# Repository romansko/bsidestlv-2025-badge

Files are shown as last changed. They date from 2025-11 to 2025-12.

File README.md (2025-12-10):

# BSidesTLV2025 Hardware CTF
Unlock the hidden secrets of the badge. What kind of secrets lie in waiting? Designed for security researchers and hardware enthusiasts, the BSidesTLV2025 badge is your ultimate mystery in digital exploration.

<p align = "center">
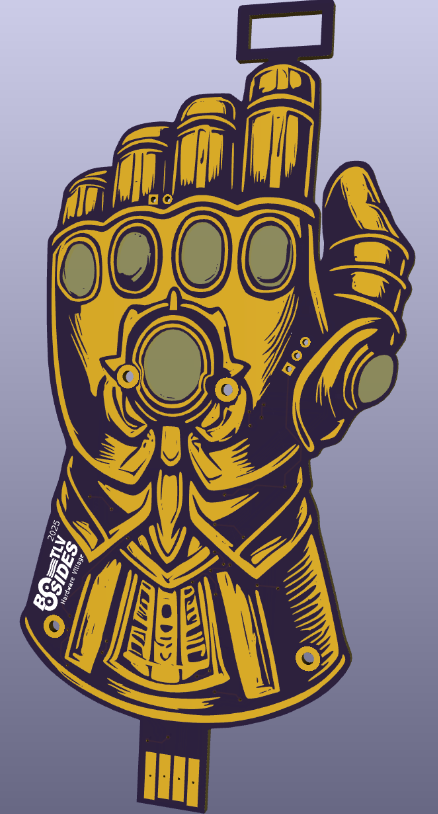
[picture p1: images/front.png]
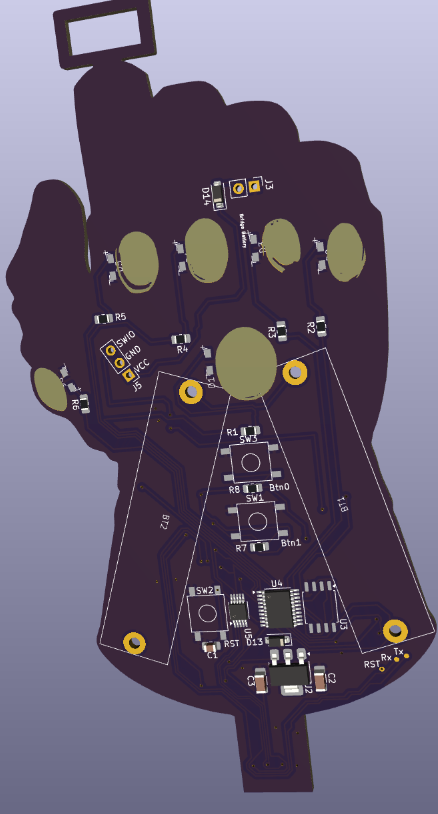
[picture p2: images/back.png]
     
</p>

### About The Project
The BSidesTLV2025 badge is a hardware hacking challenge. It is suitable for both novice and experienced tinkerers and hackers. It utilizes a low number of components to make the challenge easier to grasp, but holds in itself enough intricacies that will require the challenger a keen eye and sharp mind to solve all challenges.

To solve the challenge you will need to discover a series of flags, hidden inside the badge. Each one will help you unlock the next step in the challenge, to finally reveal the ultimate secret the badge holds.

## How to Solve
You, as the challenger, will face a couple of tricks on the hardware level. It is strongly recommended to identify which chips are used, find their datasheet and understand how they are connected. Then, dive into the software to understand how it is built and figure out what needs to be done to make the badge uncover its truth to you. All the software (except the encryption keys and the flags) is available here on this repository. It is recommended to try and reverse engineer the PCB before heading towards the `hw` folder.

### Source structure
* `aes.cpp` [AES implementation](https://github.com/kokke/tiny-AES-c)
* `main.cpp` Boot and Setup

... The rest is up to you. :-)

### You Will Need
Ultimately, no additional tools are required to solve the challenges. However, for hardcore external hacking, the following list is a recommended list of equipment that is suggested to solve the challenge:
* Multimeter
* Soldering Iron
* Jumper wires
* An external microcontroller (Any Arduino/RPi)

### Software
Please install the following software to be able to flash software to the device:
* [ch32fun](https://github.com/cnlohr/ch32fun/wiki/Installation) Follow install guide for toolchain and `minichlink` flash utility
* [Flash Update](https://swordofsecrets.com/update.html) Use online update tool to update the sword using preflashed bootloader

### Hardware
All PCB specs are provided here under `hw/`. This can be easily manufactured as well as paneled for a larger volume. There are no special requirements for this board's manufacturing process.

#### Bill of Materials
| Quantity | Component Description | Datasheet |
|---|---|---|
| 1 | CH32V003 RISC-V Microcontroller | [Datasheet](http://mcu.cz/images_articles/5007-CH32V003Reference-Manual.PDF) |
| 1 | AMS1117-3.3 LDO Voltage Regulator | [Datasheet](https://www.ti.com/lit/gpn/lm1117) |
| 1 | CH340N USB-toSerial | [Datasheet](https://cdn.sparkfun.com/assets/5/0/a/8/5/CH340DS1.PDF) |
| 1 | W25Q128JVSIQ 128MB NOR Flash | [Datasheet](https://www.mouser.co.il/datasheet/2/949/w25q128jv_revf_03272018_plus-1489608.pdf) |
| 1 | SMD 10 kOhms 0805 Resistor|  |
| 1 | SMD 100 kOhms 0805 Resistor |  |
| 3 | SMD 0.1 uF 0805 Capacitor |  |

<!-- LICENSE -->
## License

Distributed under the MIT License.

<p align="right">(<a href="#readme-top">back to top</a>)</p>

<!-- CONTACT -->
## Contact

Gili Yankovitch - [@GiliYankovitch](https://x.com/GiliYankovitch) - giliy@nyxsecurity.net

<!-- MARKDOWN LINKS & IMAGES -->
<!-- https://www.markdownguide.org/basic-syntax/#reference-style-links -->
[front]: images/front.png
[back]: images/back.png

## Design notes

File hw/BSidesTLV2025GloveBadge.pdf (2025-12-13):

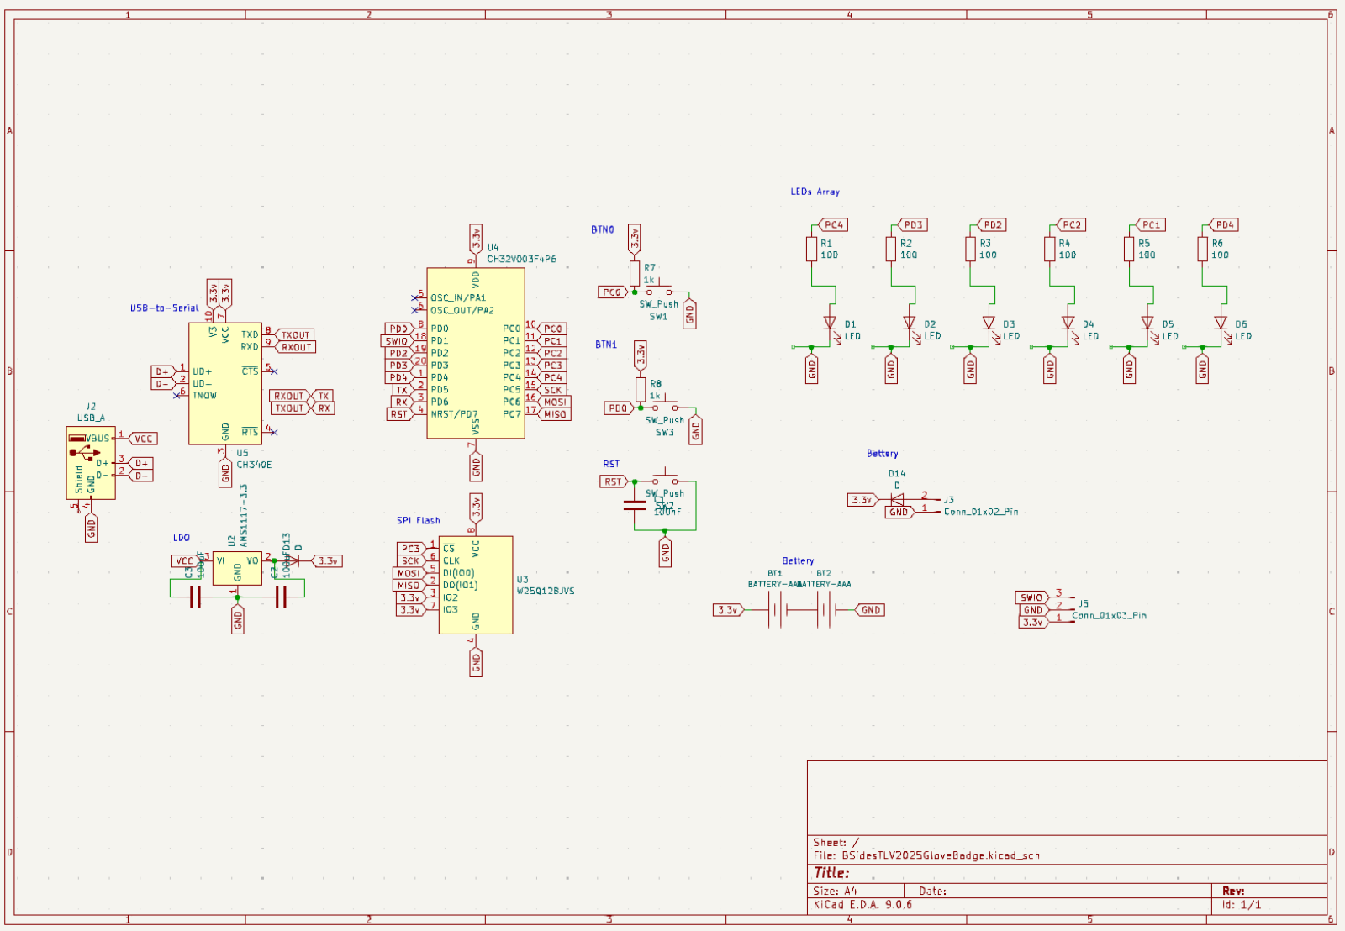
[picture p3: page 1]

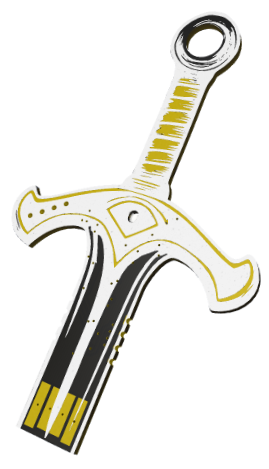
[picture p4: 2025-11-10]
images/sword.png

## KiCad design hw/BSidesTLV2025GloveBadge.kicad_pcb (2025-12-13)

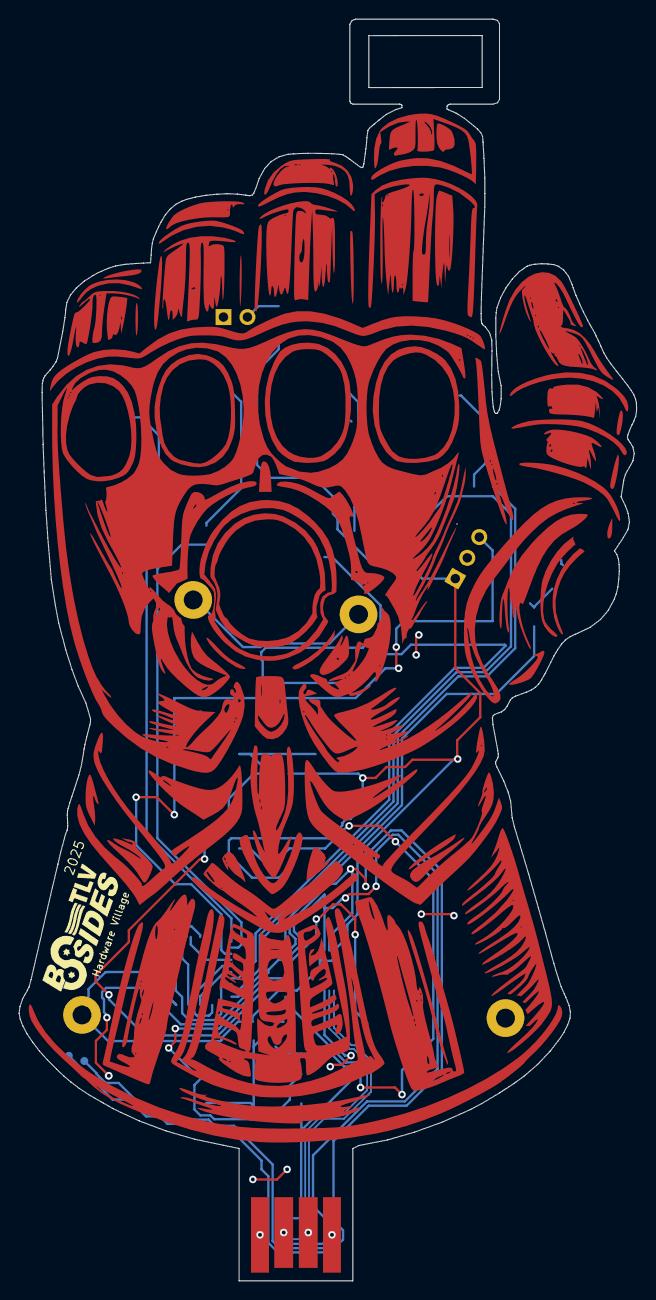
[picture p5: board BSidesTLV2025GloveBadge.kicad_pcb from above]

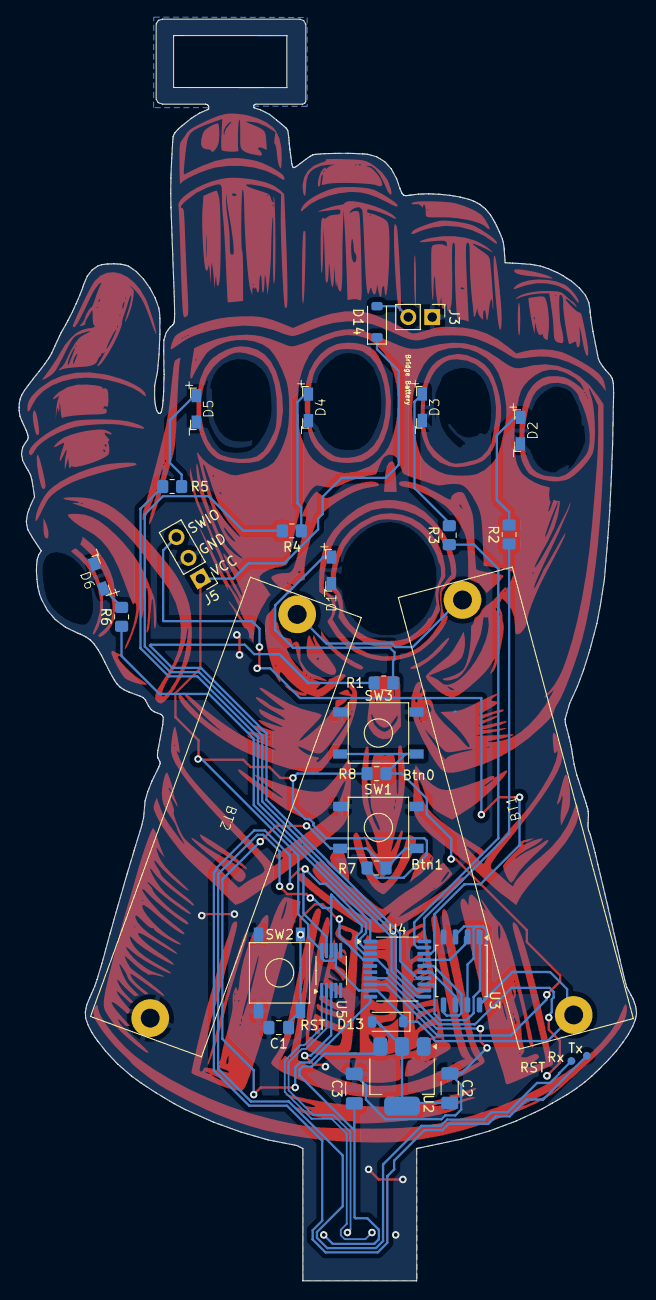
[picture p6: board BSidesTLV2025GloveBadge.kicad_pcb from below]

Board: 2 copper layers, 65.4 x 133.6 mm, 31 parts (30 on the bottom side), 30 nets.

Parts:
BT1, BT2: BATTERY-AAA; BH-AAA-A1AJ001
C1: 100nF; C_0805_2012Metric_Pad1.18x1.45mm_HandSolder
C2, C3: 100uF; C_1206_3216Metric_Pad1.33x1.80mm_HandSolder
D1, D2, D3, D4, D5, D6: LED; XL-2810
D13, D14: D; D_SOD-123
J2: USB_A; usb-PCB
J3: Conn_01x02_Pin; PinHeader_1x02_P2.54mm_Vertical
J5: Conn_01x03_Pin; PinHeader_1x03_P2.54mm_Vertical
R1, R2, R3, R4, R5, R6: 100; R_0805_2012Metric_Pad1.20x1.40mm_HandSolder
R7, R8: 1k; R_0805_2012Metric_Pad1.20x1.40mm_HandSolder
SW1, SW2, SW3: SW_Push; SMD-BTN-6x6-4Pin
U2: AMS1117-3.3; SOT-223-3_TabPin2
U3: W25Q128JVS; SOIC-8_5.23x5.23mm_P1.27mm
U4: CH32V003F4P6; TSSOP-20_4.4x6.5mm_P0.65mm
U5: CH340E; MSOP-10_3x3mm_P0.5mm

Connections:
3.3v: BT1.PWR@ (+), D13.1 (K), D14.1 (K), J5.1, R7.1, R8.1, U3.3 (IO2), U3.7 (IO3), U3.8 (VCC), U4.9 (VDD), U5.7 (VCC), U5.10 (V3)
D+: J2.3 (D+), U5.1 (UD+)
D-: J2.2 (D-), U5.2 (UD-)
GND: BT2.GND@ (-), C1.2, C2.1, C3.2, D1.1 (K), D2.1 (K), D3.1 (K), D4.1 (K), D5.1 (K), D6.1 (K), J2.4 (GND), J3.1, J5.2, SW1.1, SW2.1, SW3.1, U2.1 (GND), U3.4 (GND), U4.7 (VSS), U5.3 (GND)
MISO: U3.2 (DO(IO1)), U4.17 (PC7)
MOSI: U3.5 (DI(IO0)), U4.16 (PC6)
unnamed: BT1.GND@ (-), BT2.PWR@ (+)
unnamed: D1.2 (A), R1.2
unnamed: D2.2 (A), R2.2
unnamed: D3.2 (A), R3.2
unnamed: D4.2 (A), R4.2
unnamed: D5.2 (A), R5.2
unnamed: D6.2 (A), R6.2
unnamed: C2.2, D13.2 (A), U2.2 (VO)
unnamed: D14.2 (A), J3.2
PC0: R7.2, SW1.2, U4.10 (PC0)
PC1: R5.1, U4.11 (PC1)
PC2: R4.1, U4.12 (PC2)
PC3: U3.1 (~CS), U4.13 (PC3)
PC4: R1.1, U4.14 (PC4)
PD0: R8.2, SW3.2, U4.8 (PD0)
PD2: R3.1, U4.19 (PD2)
PD3: R2.1, U4.20 (PD3)
PD4: R6.1, U4.1 (PD4)
RST: C1.1, SW2.2, U4.4 (NRST/PD7)
RX: U4.3 (PD6), U5.8 (TXD)
RXOUT: U4.2 (PD5), U5.9 (RXD)
SCK: U3.6 (CLK), U4.15 (PC5)
SWIO: J5.3, U4.18 (PD1)
VCC: C3.1, J2.1 (VBUS), U2.3 (VI)

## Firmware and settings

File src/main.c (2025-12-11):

#include "include/led.h"
#include <stdio.h>
#include <stdint.h>
#include <ch32v003fun.h>
#include <build-mode.h>
#include <aes.h>
#include <armory.h>
#include <keys.h>
#include <uart.h>
#include <flash.h>
#include <cli.h>
#include <led.h>
#include <button.h>
#include <minigame.h>

#define CH32V003_SPI_SPEED_HZ (100000000/3)
#define CH32V003_SPI_DIRECTION_2LINE_TXRX
#define CH32V003_SPI_CLK_MODE_POL0_PHA0
#define CH32V003_SPI_NSS_SOFTWARE_ANY_MANUAL // #define CH32V003_SPI_NSS_HARDWARE_PC0
#define CH32V003_SPI_IMPLEMENTATION
#include <ch32v003_SPI.h>

#ifdef SOLVE
#include "solve.h"
#endif
#define PIN_FLASH_CS PC3

#define CHALLENGE_STATUS_ADDR 0x900000
#define RESET_MAX_JIFFIES 1000000

uint32_t initial_jiffies = 0;

struct challenge_status_s
{
    uint32_t jiffies;
    uint32_t count;
} status;

void init_pins(void)
{
    // Initialize LEDs
    led_init();
    
    // Initialize buttons
    button_init();
}


void handleChallengeStatus()
{
    flash_read(CHALLENGE_STATUS_ADDR, &status, sizeof(struct challenge_status_s));

    // First time!
    if ((status.jiffies == 0xffffffff) && (status.count == 0xffffffff))
    {
        status.count = 0;

    }
    // New Reset
    else if (((SysTick->CNT - initial_jiffies) <= status.jiffies) && (status.jiffies < RESET_MAX_JIFFIES))
    {
        // Increase reset count
        status.count++;
    }

    status.jiffies = SysTick->CNT - initial_jiffies;

    flash_erase_block(CHALLENGE_STATUS_ADDR);
    flash_write(CHALLENGE_STATUS_ADDR, &status, sizeof(struct challenge_status_s));
}

void resetChallengeStatus()
{
    flash_erase_block(CHALLENGE_STATUS_ADDR);
}

int setup()
{
    int err = -1;
    
    initial_jiffies = SysTick->CNT;

    if (flash_init(PIN_FLASH_CS))
    {
        blink_finger(PIN_HAND_LED, 1);
        printf("Flash initialization success\r\n");

        blink_finger(PIN_HAND_LED,2);

        flash_load_ext_cmds();
    }
    else
    {
        printf("Flash initialization failed\r\n");

        blink_finger(PIN_HAND_LED, 4);

        turn_on_led(PIN_HAND_LED);

        goto error;
    }

    handleChallengeStatus();

	printf("Initializing (Reset count: %ld)...\r\n", status.count);

    blink_finger(PIN_HAND_LED, 1);

    // blink_finger(PIN_HAND_LED,status.count);

    if (status.count >= 3)
    {

        printf("Resetting challenge...\r\n");
        resetChallengeStatus();

        printf("Resetting quest...\r\n");
        setupQuest();

        printf("Done.\r\n");

        turn_on_led(PIN_HAND_LED);

        // goto error;
    }

#ifdef SOLVE
    solve();
#else
#ifndef GOLD_CHALLENGE
    plunderLoad();
#endif

    printf(INTRO_MESSAGE "\r\n");
#endif

    err = 0;
error:
    return err;
}

void challenges(char * challenge)
{
    handleChallengeStatus();
    // blink_finger(PIN_HAND_LED,1);

#ifdef SOLVE
    printf("Done solving.\r\n");
#else

#ifdef GOLD_CHALLENGE
    attempts(challenge);

    if (persuasion() < 0)
    {
        printf("Probably not...\r\n");

        goto done;
    }

#else
    if (palisade() < 0)
    {
        challenge_failure(PIN_RING_LED);
        printf("This is not the right header..." "\r\n");

        goto done;
    }
    challenge_success(PIN_RING_LED);

    if (parapet() < 0)
    {
        challenge_failure(PIN_MIDDLE_LED);
        printf("Invalid Header" "\r\n");
        goto done;
    }
    challenge_success(PIN_MIDDLE_LED);

    int err = postern();

    if (err < 0)
    {
        challenge_failure(PIN_INDEX_LED);
        printf("Error in response." "\r\n");
        goto done;
    }
    else if (err == 1)
    {
        challenge_failure(PIN_INDEX_LED);
        printf("Invalid padding" "\r\n");

        goto done;
    }

    challenge_success(PIN_INDEX_LED);
    digForTreasure();

    if (treasuryVisit() < 0)
    {
        challenge_failure(PIN_THUMB_LED);
        printf("The secret is still safe!" "\r\n");
    }
    else
    {
        challenge_success(PIN_THUMB_LED);
        challenge_success(PIN_HAND_LED);
        printf("THE SECRET IS REVEALED!" "\r\n");
        all_challenges_success();
    }
#endif
    blink_finger(PIN_HAND_LED, 1);

done:
    // Delay_Ms(1000);
    return;
#endif
}

unsigned int xtoi(char c)
{
    switch (c)
    {
        case 'F':
        case 'E':
        case 'D':
        case 'C':
        case 'B':
        case 'A':
            return 10 + (c - 'A');
        case 'f':
        case 'e':
        case 'd':
        case 'c':
        case 'b':
        case 'a':
            return 10 + (c - 'a');
        case '9':
        case '8':
        case '7':
        case '6':
        case '5':
        case '4':
        case '3':
        case '2':
        case '1':
        case '0':
            return c - '0';
        default:
            return 0xff;
    }

    return 0xff;
}

static uint32_t atox(char * c)
{
    int v;
    uint32_t total = 0;

    while ((v = xtoi(*c)) != 0xff)
    {
        total = total * 16 + v;

        c++;
    }

    return total;
}

int strcmp(const char *l, const char *r);
int memcmp(const void *vl, const void *vr, size_t n);

static void parseCmd(char * data, size_t len)
{
    size_t i;

    if (!memcmp(CMD_SOLVE, data, sizeof(CMD_SOLVE) - 1))
    {
        challenges(data + sizeof(CMD_SOLVE));
    }
    if (!strcmp(CMD_ASSERT, data))
    {
        funDigitalWrite(PIN_FLASH_CS, FUN_LOW)
    }
    else if (!strcmp(CMD_RELEASE, data))
    {
        funDigitalWrite(PIN_FLASH_CS, FUN_HIGH)
    }
    else if (!strcmp(CMD_BEGIN, data))
    {
        SPI_init();
        SPI_begin_8();
    }
    else if (!strcmp(CMD_END, data))
    {
        SPI_end();
    }
    else if (!strcmp(CMD_RESET, data))
    {
        resetChallengeStatus();
        setupQuest();
    }
    else if (!memcmp(CMD_DATA, data, 4))
    {
        if (len <= sizeof(CMD_DATA) - 1)
        {
            return;
        }

        // Data starts only after command
        i = 4;

        while (i < len)
        {
            if (xtoi(data[i]) == 0xff)
            {
                i++;
                continue;
            }

            uint8_t in = atox(&data[i]);

            uint8_t out = SPI_transfer_8(in);

            printf("%02x ", out);

            // Find the next non-number, which follows a number
            // Finish the current number
            while (xtoi(data[i]) != 0xff)
            {
                i++;
            }

            // Skip all the next non-numbers
            while (xtoi(data[i]) == 0xff)
            {
                i++;
            }
        }

        printf("\r\n");
    }
}

static void handleSerialRead()
{
    char data[128];
    size_t len = 0;

    printf(">> ");

    while (len < sizeof(data) - 1)
    {
        data[len++] = _gets();

        if ((data[len - 1] == '\r') || (data[len - 1] == '\n'))
        {
            printf("\r\n");

            break;
        }
        else
        {
            printf("%c", data[len - 1]);
        }
    }

    data[len - 1] = '\0';

    // Parse input
    parseCmd(data, len);

    printf("\r\n");
}








int main()
{
	// Enable GPIOs
	funGpioInitAll();

    init_pins();

    // check if button 1 is pressed
    if (!funDigitalRead(PIN_BTN_1))
    {
        printf("Mini game mode\r\n");
        boot_sequence(30);
        for (int i = 10; i >= 1; i--){
            printf("Filling LEDs with %d ms delay\r\n", i*10);
            led_fill_minigame(i*10);
        }
        printf("Mini game mode completed\r\n");
        Delay_Ms(400);
        all_challenges_success();
    }


    boot_sequence(75);
    

    
    if (button_challenge()){
        challenge_success(PIN_LITTLE_LED);
    }

    Delay_Ms(400);

    if (setup() < 0)
    {
        while (1);
    }

    
    while (1)
    {
        handleSerialRead();
    }
}

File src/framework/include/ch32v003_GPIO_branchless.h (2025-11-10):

// 2023-06-26 recallmenot

//######## necessities

// include guards
#ifndef CH32V003_GPIO_BR_H
#define CH32V003_GPIO_BR_H

// includes
#include <stdint.h>								//uintN_t support
#include <ch32v003fun.h>



/*######## library description
This is a speedy and light GPIO library due to
	static inlining of most functions
	compile-time abstraction
	branchless where it counts
*/



/*######## library usage and configuration

first, enable the desired port.

digital usage is quite Arduino-like:
pinMode
digitalWrite
digitalWrite_lo
digitalWrite_hi
digitalRead

pins are referenced as a single byte, ST-style:
the upper 4 bytes specify the port, where A is 0, C is 2 etc.
the lower 4 bytes specify the pin
both are used as uint4_t, not as 4 individual bits, allowing to address up to 16 pins on up to 16 ports.
this style of referencing a pin is called "GPIOv" in this library.

additionally, there are functions to operate an entire port at once
this can be useful where setting all pins one by one would be too inefficient / unnecessary
an example where this may be useful: https://www.youtube.com/watch?v=cy6o8TrDUFU
GPIO_port_digitalWrite
GPIO_port_digitalRead



analog-to-digital usage is almost Arduino-like:
pinMode
ADCinit
analogRead

By default, this library inserts a delay of 300 µs between configuration of the ADC input mux and the time the conversion starts.
This serves to counteract the high input impedance of the ADC, especially if it is increased by external resistors.
The input impedance of port A appears to be especially large.
You may modify it to your liking using the following define before including this library.
#define GPIO_ADC_MUX_DELAY 1200

GPIO_ADC_sampletime controls the time each conversion is granted, by default it is GPIO_ADC_sampletime_241cy_default, all options originate from the GPIO_ADC_sampletimes enum.
To alter it, you have 3 options:
 * `#define GPIO_ADC_sampletime GPIO_ADC_sampletime_43cy` before including this library
 * call the GPIO_ADC_set_sampletime function-like macro to momentarrily set it for one channel
 * call the GPIO_ADC_set_sampletimes_all function-like macro to to momentarrily set it for all channels

You may also disable the ADC to save power between infrequent measurements.



digital-to-analog (PWM) usage is quite different:
pinMode
GPIO_timX_map
GPIO_timX_init
GPIO_timX_enableCH
GPIO_timX_analogWrite

This is due to the fact that the CH32V003 has 2 timers, which each can be connected to 4 pre-defined sets (mappings) of pins.
Then you address the 4 channels of the timers, instead of the pins.

By default, the timers will be configured to count up to 2^10, which is 10 bits or 1024 discrete steps.
You may alter this to suit your needs, for example to an 8 bit resolution (256 discrete steps).
Insert this before including this library:
#define GPIO_timer_resolution (1 << 8)

By default, the timers will operate with a clock prescaler of 2 but you may choose 1 or 4 if you wish to alter the speed.
Insert this before including this library:
#define GPIO_timer_prescaler TIM_CKD_DIV1;		// APB_CLOCK / 1024 / 1 = 46.9kHz

You may calculate the base frequency of the timer (the rate of repetition of your signal) like follows:
fpwm = APB_CLOCK / resolution / prescaler
This puts the defaults at an inaudible 23.4kHz.
The higher the frequency, the greater the EMI radiation will be.
With low frequencies, say below 1000Hz, LEDs may exhibit perceivable flicker.

Since this library enables compare capture preload (OCxPE of CHCTLRy), writing a value into the compare register using analogWrite will automatically apply it (=load into shadow register) when the timer starts its next cycle.
This avoids a bug whereby writing a compare value lower than the current counter value, the output will glitch high for the next cycle, resulting in flickery updates.
Writing `TIMx->SWEVGR |= TIM_UG` will immediately update the shadow register and cause the same issue.

*/



//######## ports, pins and states: use these for the functions below!

#define GPIOv_from_PORT_PIN( GPIO_port_n, pin )

enum GPIO_port_n {
	GPIO_port_A = 0b00,
	GPIO_port_C = 0b10,
	GPIO_port_D = 0b11,
};

enum GPIO_pinModes {
	GPIO_pinMode_I_floating,
	GPIO_pinMode_I_pullUp,
	GPIO_pinMode_I_pullDown,
	GPIO_pinMode_I_analog,
	GPIO_pinMode_O_pushPull,
	GPIO_pinMode_O_openDrain,
	GPIO_pinMode_O_pushPullMux,
	GPIO_pinMode_O_openDrainMux,
};

enum lowhigh {
	low,
	high,
};

// analog inputs
enum GPIO_analog_inputs {
	GPIO_Ain0_A2,
	GPIO_Ain1_A1,
	GPIO_Ain2_C4,
	GPIO_Ain3_D2,
	GPIO_Ain4_D3,
	GPIO_Ain5_D5,
	GPIO_Ain6_D6,
	GPIO_Ain7_D4,
	GPIO_AinVref,
	GPIO_AinVcal,
};

// how many cycles the ADC shall sample the input for (speed vs precision)
enum GPIO_ADC_sampletimes {
	GPIO_ADC_sampletime_3cy,
	GPIO_ADC_sampletime_9cy,
	GPIO_ADC_sampletime_15cy,
	GPIO_ADC_sampletime_30cy,
	GPIO_ADC_sampletime_43cy,
	GPIO_ADC_sampletime_57cy,
	GPIO_ADC_sampletime_73cy,
	GPIO_ADC_sampletime_241cy_default,
};
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

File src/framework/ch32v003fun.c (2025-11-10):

// Mixture of embedlibc, and ch32v00x_startup.c



// Use with newlib headers.
// Mixture of weblibc, mini-printf and ???

#include <stdio.h>
#include <string.h>
#include <stdarg.h>
#include <limits.h>
#include <stdint.h>
#include <ch32v003fun.h>

int __attribute__(( section(".bootloader.data") )) errno;

int mini_vsnprintf(char *buffer, unsigned int buffer_len, const char *fmt, va_list va);
int mini_vpprintf(int (*puts)(char* s, int len, void* buf), void* buf, const char *fmt, va_list va);

static int __puts_uart(char *s, int len, void *buf)
{
	_write( 0, s, len );
	return len;
}

int printf(const char* format, ...)
{
	va_list args;
	va_start( args, format );
	int ret_status = mini_vpprintf(__puts_uart, 0, format, args);
	va_end( args );
	return ret_status;
}

int vprintf(const char* format, va_list args)
{
	return mini_vpprintf(__puts_uart, 0, format, args);
}

int snprintf(char * buffer, unsigned int buffer_len, const char* format, ...)
{
	va_list args;
	va_start( args, format );
	int ret = mini_vsnprintf( buffer, buffer_len, format, args );
	va_end( args );
	return ret;
}

/* Some stuff from MUSL


----------------------------------------------------------------------
Copyright © 2005-2020 Rich Felker, et al.

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
THE SOFTWARE IS PROVIDED "AS IS", WITHOUT WARRANTY OF ANY KIND,
EXPRESS OR IMPLIED, INCLUDING BUT NOT LIMITED TO THE WARRANTIES OF
MERCHANTABILITY, FITNESS FOR A PARTICULAR PURPOSE AND NONINFRINGEMENT.
IN NO EVENT SHALL THE AUTHORS OR COPYRIGHT HOLDERS BE LIABLE FOR ANY
CLAIM, DAMAGES OR OTHER LIABILITY, WHETHER IN AN ACTION OF CONTRACT,
TORT OR OTHERWISE, ARISING FROM, OUT OF OR IN CONNECTION WITH THE
SOFTWARE OR THE USE OR OTHER DEALINGS IN THE SOFTWARE.
----------------------------------------------------------------------

*/

/*
 * mbstate_t is an opaque object to keep conversion state, during multibyte
 * stream conversions.  The content must not be referenced by user programs.
 */

#define CURRENT_UTF8 0
#define IS_CODEUNIT(c) ((unsigned)(c)-0xdf80 < 0x80)
#define MB_CUR_MAX (CURRENT_UTF8 ? 4 : 1)

typedef void * mbstate_t;

#ifdef UNICODE
size_t wcrtomb(char *restrict s, wchar_t wc, mbstate_t *restrict st)
{
	if (!s) return 1;
	if ((unsigned)wc < 0x80) {
		*s = wc;
		return 1;
	} else if (MB_CUR_MAX == 1) {
		if (!IS_CODEUNIT(wc)) {
			errno = 0x02; // EILSEQ
			return -1;
		}
		*s = wc;
		return 1;
	} else if ((unsigned)wc < 0x800) {
		*s++ = 0xc0 | (wc>>6);
		*s = 0x80 | (wc&0x3f);
		return 2;
	} else if ((unsigned)wc < 0xd800 || (unsigned)wc-0xe000 < 0x2000) {
		*s++ = 0xe0 | (wc>>12);
		*s++ = 0x80 | ((wc>>6)&0x3f);
		*s = 0x80 | (wc&0x3f);
		return 3;
	} else if ((unsigned)wc-0x10000 < 0x100000) {
		*s++ = 0xf0 | (wc>>18);
		*s++ = 0x80 | ((wc>>12)&0x3f);
		*s++ = 0x80 | ((wc>>6)&0x3f);
		*s = 0x80 | (wc&0x3f);
		return 4;
	}
	errno = 0x02;//EILSEQ;
	return -1;
}
int wctomb(char *s, wchar_t wc)
{
	if (!s) return 0;
	return wcrtomb(s, wc, 0);
}
#endif
size_t strlen(const char *s) { const char *a = s;for (; *s; s++);return s-a; }
size_t strnlen(const char *s, size_t n) { const char *p = memchr(s, 0, n); return p ? p-s : n;}
void __attribute__(( section(".topflash.text") )) *memset(void *dest, int c, size_t n) { unsigned char *s = dest; for (; n; n--, s++) *s = c; return dest; }
char *strcpy(char *d, const char *s) { for (; (*d=*s); s++, d++); return d; }
char *strncpy(char *d, const char *s, size_t n) { for (; n && (*d=*s); n--, s++, d++); return d; }
int strcmp(const char *l, const char *r)
{
	for (; *l==*r && *l; l++, r++);
	return *(unsigned char *)l - *(unsigned char *)r;
}
int strncmp(const char *_l, const char *_r, size_t n)
{
	const unsigned char *l=(void *)_l, *r=(void *)_r;
	if (!n--) return 0;
	for (; *l && *r && n && *l == *r ; l++, r++, n--);
	return *l - *r;
}

static char *twobyte_strstr(const unsigned char *h, const unsigned char *n)
{
	uint16_t nw = n[0]<<8 | n[1], hw = h[0]<<8 | h[1];
	for (h++; *h && hw != nw; hw = hw<<8 | *++h);
	return *h ? (char *)h-1 : 0;
}

static char *threebyte_strstr(const unsigned char *h, const unsigned char *n)
{
	uint32_t nw = (uint32_t)n[0]<<24 | n[1]<<16 | n[2]<<8;
	uint32_t hw = (uint32_t)h[0]<<24 | h[1]<<16 | h[2]<<8;
	for (h+=2; *h && hw != nw; hw = (hw|*++h)<<8);
	return *h ? (char *)h-2 : 0;
}

static char *fourbyte_strstr(const unsigned char *h, const unsigned char *n)
{
	uint32_t nw = (uint32_t)n[0]<<24 | n[1]<<16 | n[2]<<8 | n[3];
	uint32_t hw = (uint32_t)h[0]<<24 | h[1]<<16 | h[2]<<8 | h[3];
	for (h+=3; *h && hw != nw; hw = hw<<8 | *++h);
	return *h ? (char *)h-3 : 0;
}

#define MAX(a,b) ((a)>(b)?(a):(b))
#define MIN(a,b) ((a)<(b)?(a):(b))

#define BITOP(a,b,op) \
 ((a)[(size_t)(b)/(8*sizeof *(a))] op (size_t)1<<((size_t)(b)%(8*sizeof *(a))))

static char *twoway_strstr(const unsigned char *h, const unsigned char *n)
{
	const unsigned char *z;
	size_t l, ip, jp, k, p, ms, p0, mem, mem0;
	size_t byteset[32 / sizeof(size_t)] = { 0 };
	size_t shift[256];

	/* Computing length of needle and fill shift table */
	for (l=0; n[l] && h[l]; l++)
		BITOP(byteset, n[l], |=), shift[n[l]] = l+1;
	if (n[l]) return 0; /* hit the end of h */

	/* Compute maximal suffix */
	ip = -1; jp = 0; k = p = 1;
	while (jp+k<l) {
		if (n[ip+k] == n[jp+k]) {
			if (k == p) {
				jp += p;
				k = 1;
			} else k++;
		} else if (n[ip+k] > n[jp+k]) {
			jp += k;
			k = 1;
			p = jp - ip;
		} else {
			ip = jp++;
			k = p = 1;
		}
	}
	ms = ip;
	p0 = p;

	/* And with the opposite comparison */
	ip = -1; jp = 0; k = p = 1;
	while (jp+k<l) {
		if (n[ip+k] == n[jp+k]) {
			if (k == p) {
				jp += p;
				k = 1;
			} else k++;
		} else if (n[ip+k] < n[jp+k]) {
			jp += k;
			k = 1;
			p = jp - ip;
		} else {
			ip = jp++;
			k = p = 1;
		}
	}
	if (ip+1 > ms+1) ms = ip;
	else p = p0;

	/* Periodic needle? */
	if (memcmp(n, n+p, ms+1)) {
		mem0 = 0;
		p = MAX(ms, l-ms-1) + 1;
	} else mem0 = l-p;
	mem = 0;

	/* Initialize incremental end-of-haystack pointer */
	z = h;

	/* Search loop */
	for (;;) {
		/* Update incremental end-of-haystack pointer */
		if (z-h < l) {
			/* Fast estimate for MAX(l,63) */
			size_t grow = l | 63;
			const unsigned char *z2 = memchr(z, 0, grow);
			if (z2) {
				z = z2;
				if (z-h < l) return 0;
			} else z += grow;
		}

		/* Check last byte first; advance by shift on mismatch */
		if (BITOP(byteset, h[l-1], &)) {
			k = l-shift[h[l-1]];
			if (k) {
				if (k < mem) k = mem;
				h += k;
				mem = 0;
				continue;
			}
		} else {
			h += l;
			mem = 0;
			continue;
		}

		/* Compare right half */
		for (k=MAX(ms+1,mem); n[k] && n[k] == h[k]; k++);
		if (n[k]) {
			h += k-ms;
			mem = 0;
			continue;
		}
		/* Compare left half */
		for (k=ms+1; k>mem && n[k-1] == h[k-1]; k--);
		if (k <= mem) return (char *)h;
		h += p;
		mem = mem0;
	}
}
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

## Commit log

2025-11-24 Add LED fill minigame with automatic restart on failure
    This commit introduces a new interactive minigame where users must hold
    a button and release it precisely when all 6 LEDs are lit.
    Features:
    - LED Fill Minigame: Players hold BTN_0 while LEDs fill sequentially
    (LITTLE, RING, MIDDLE, INDEX, THUMB, HAND) with 100ms delay between each
    - Timing Challenge: Goal is to release the button when all 6 LEDs are lit
    - Automatic Restart: Game automatically restarts on failure, looping until
    success is achieved
    - Visual Feedback:
    * Success: All LEDs blink 6 times, then turn off
    * Failure (early release): LEDs that were lit blink 3 times
    * Failure (held too long): LEDs turn off in reverse o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
    [button.c, led.c, led.h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]
2025-11-24 Add configurable fill rate and progressive difficulty minigame mode
    This commit enhances the LED fill minigame with configurable difficulty
    levels and a progressive challenge mode that tests players across multiple
    speed settings.
    Key Features:
    - Configurable Fill Rate: minigame now accepts fill_rate_ms parameter
    to control LED fill speed (replaces hardcoded 100ms delay)
    - Progressive Difficulty Mode: Activated when BTN_1 is pressed at startup
    - Runs minigame with decreasing fill rates: 100ms → 10ms (10ms steps)
    - Tests player skill across 10 difficulty levels
    - Each level must be completed before advancing
    - Dynamic Grace Period: Grace period for button release now scales with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
    [main.c]
2025-12-11 chore: Fixing commands action
    [main.c]
2025-12-13 chore: Updating the schematics to the accurate glove hw
    [BSidesTLV2025GloveBadge.kicad_pcb, BSidesTLV2025GloveBadge.kicad_sch, SwordOfSecretsUSBProd.kicad_pcb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]

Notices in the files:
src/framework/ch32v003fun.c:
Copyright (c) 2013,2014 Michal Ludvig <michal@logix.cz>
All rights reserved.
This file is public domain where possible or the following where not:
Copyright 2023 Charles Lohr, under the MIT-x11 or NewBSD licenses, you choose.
